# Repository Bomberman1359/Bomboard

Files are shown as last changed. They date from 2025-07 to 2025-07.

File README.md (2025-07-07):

# Bomboard
This is my cost efficient, custom keyboard made by me. As my first project, I named it Bomboard.

I made this project not only for the Highway programs, but also to gain experience in creating my own electronics.
I wanted to learn more about schematics, wiring, PCB, and 3D modeling. As someone that does not spend money on buying keyboards I figured it would be cool to create my own!

## Schematic
Screenshot 2025-07-03 at 6 05 30 PM

## PCB
Screenshot 2025-07-03 at 5 30 22 PM

## Case
Screenshot 2025-07-04 at 12 51 43 PM

## Case and PCB combined 
Screenshot 2025-07-06 at 5 43 42 PM

## BOM
| Item | Quantity | Vendor | Total Price |
| :--- | :---: | :----- | ---: |
| PCB | 1 | JLCPB | $74.23 |
| Raspberry Pi Pico | 1 | [Seeed Studio](https://www.seeedstudio.com/Raspberry-Pi-Pico-2-p-5940.html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) | $5.00 |
| Key switches |  64  |  [Mechanical](https://mechanicalkeyboards.com/products/cherry-mx2a-blue-60g-clicky?_pos=1&_fid=016d7ed23&_ss=c)| $25.60 |
| Rotary Encoder | 1 | [SynthCube](https://synthcube.com/rotary-encoder/?gQT=1) | $2.95 | 
| Stabilizer set | 1 | [Divinikey](https://jlcpcb.com/) | $11.00 |
| Keycaps Set| 1 | [Amazon](https://www.amazon.com/Womier-Pudding-Keycaps-100-Percent/dp/B0DB4Z6DMS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) | $14.99 |

Net Total Cost: $133.77

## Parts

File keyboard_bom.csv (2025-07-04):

Item | Quantity | Vendor | Total Price
PCB | 1 | JLCPB | $74.23
Raspberry Pi Pico | 1 | Seeed Studio | $5.00
Key switches | 64 | Mechanical | $25.60
Rotary Encoder | 1 | SynthCube | $2.95
Stabilizer set | 1 | Divinikey | $11.00
Keycaps Set | 1 | Amazon | $14.99
Net Total Cost |  |  | $133.77

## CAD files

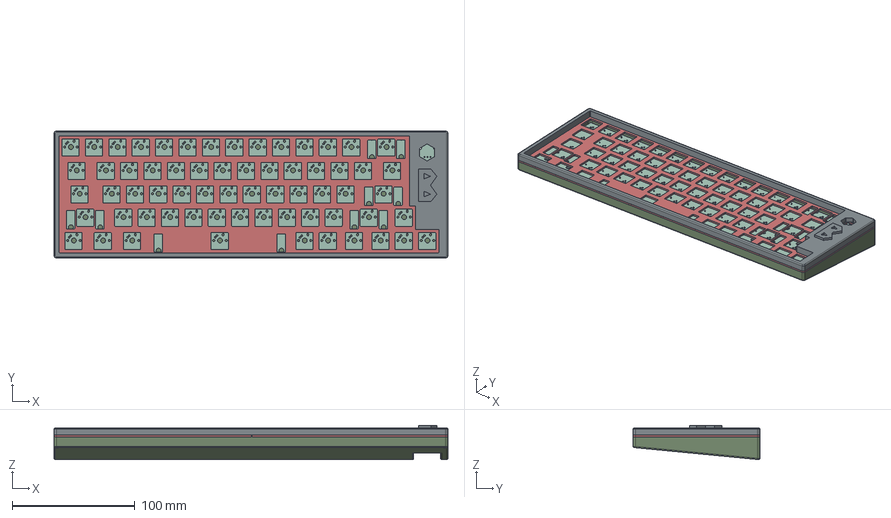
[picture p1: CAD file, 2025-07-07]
Case/keyboardCase_PCBassembly.step
321.0 x 103.5 x 27.9 mm
D_A-405_P7.62mm_Horizontal x 65
keyboard_PCB
Bottom
Top
Plate

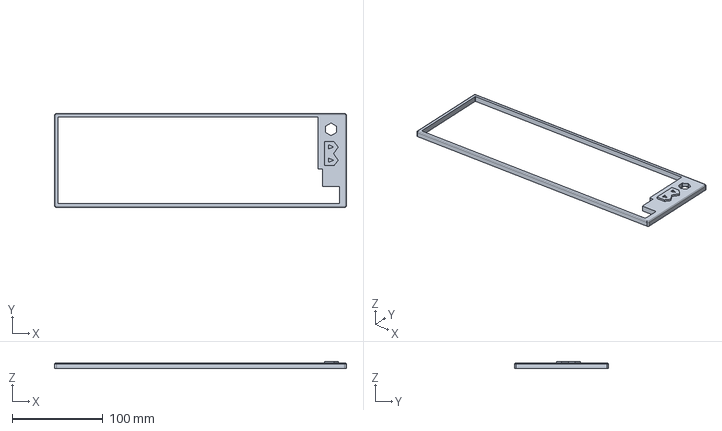
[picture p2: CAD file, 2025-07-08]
Production/3D-Printing (case)/Case_top.step
321.0 x 103.5 x 8.00 mm

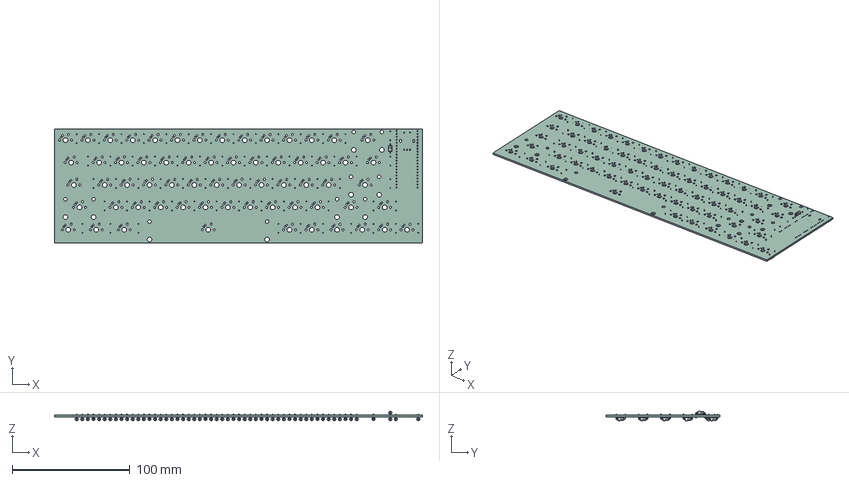
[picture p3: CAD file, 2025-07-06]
Case/keyboard.step
313.0 x 96.8 x 8.10 mm
D_A-405_P7.62mm_Horizontal x 65
keyboard_PCB

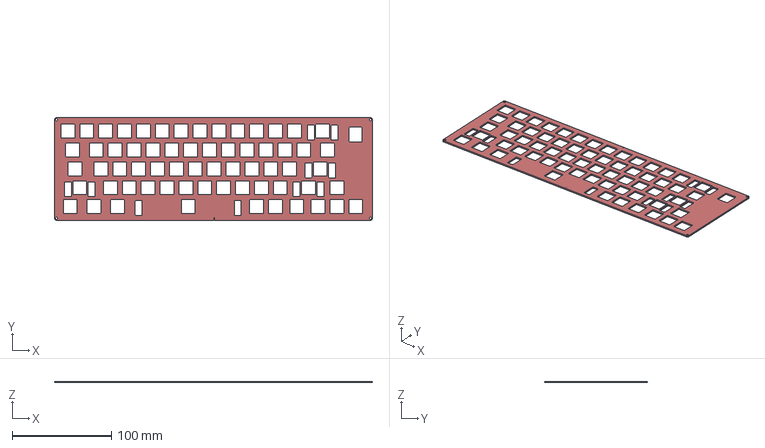
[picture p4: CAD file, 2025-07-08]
Production/3D-Printing (case)/Case_plate.step
321.0 x 103.5 x 1.50 mm

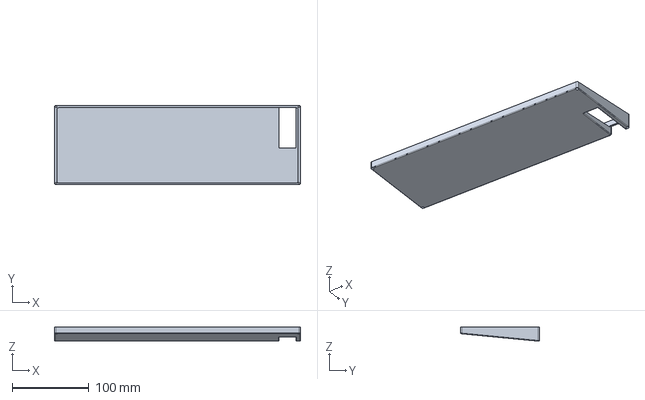
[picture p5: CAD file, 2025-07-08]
Production/3D-Printing (case)/Case_bottom.step
321.0 x 103.5 x 18.9 mm

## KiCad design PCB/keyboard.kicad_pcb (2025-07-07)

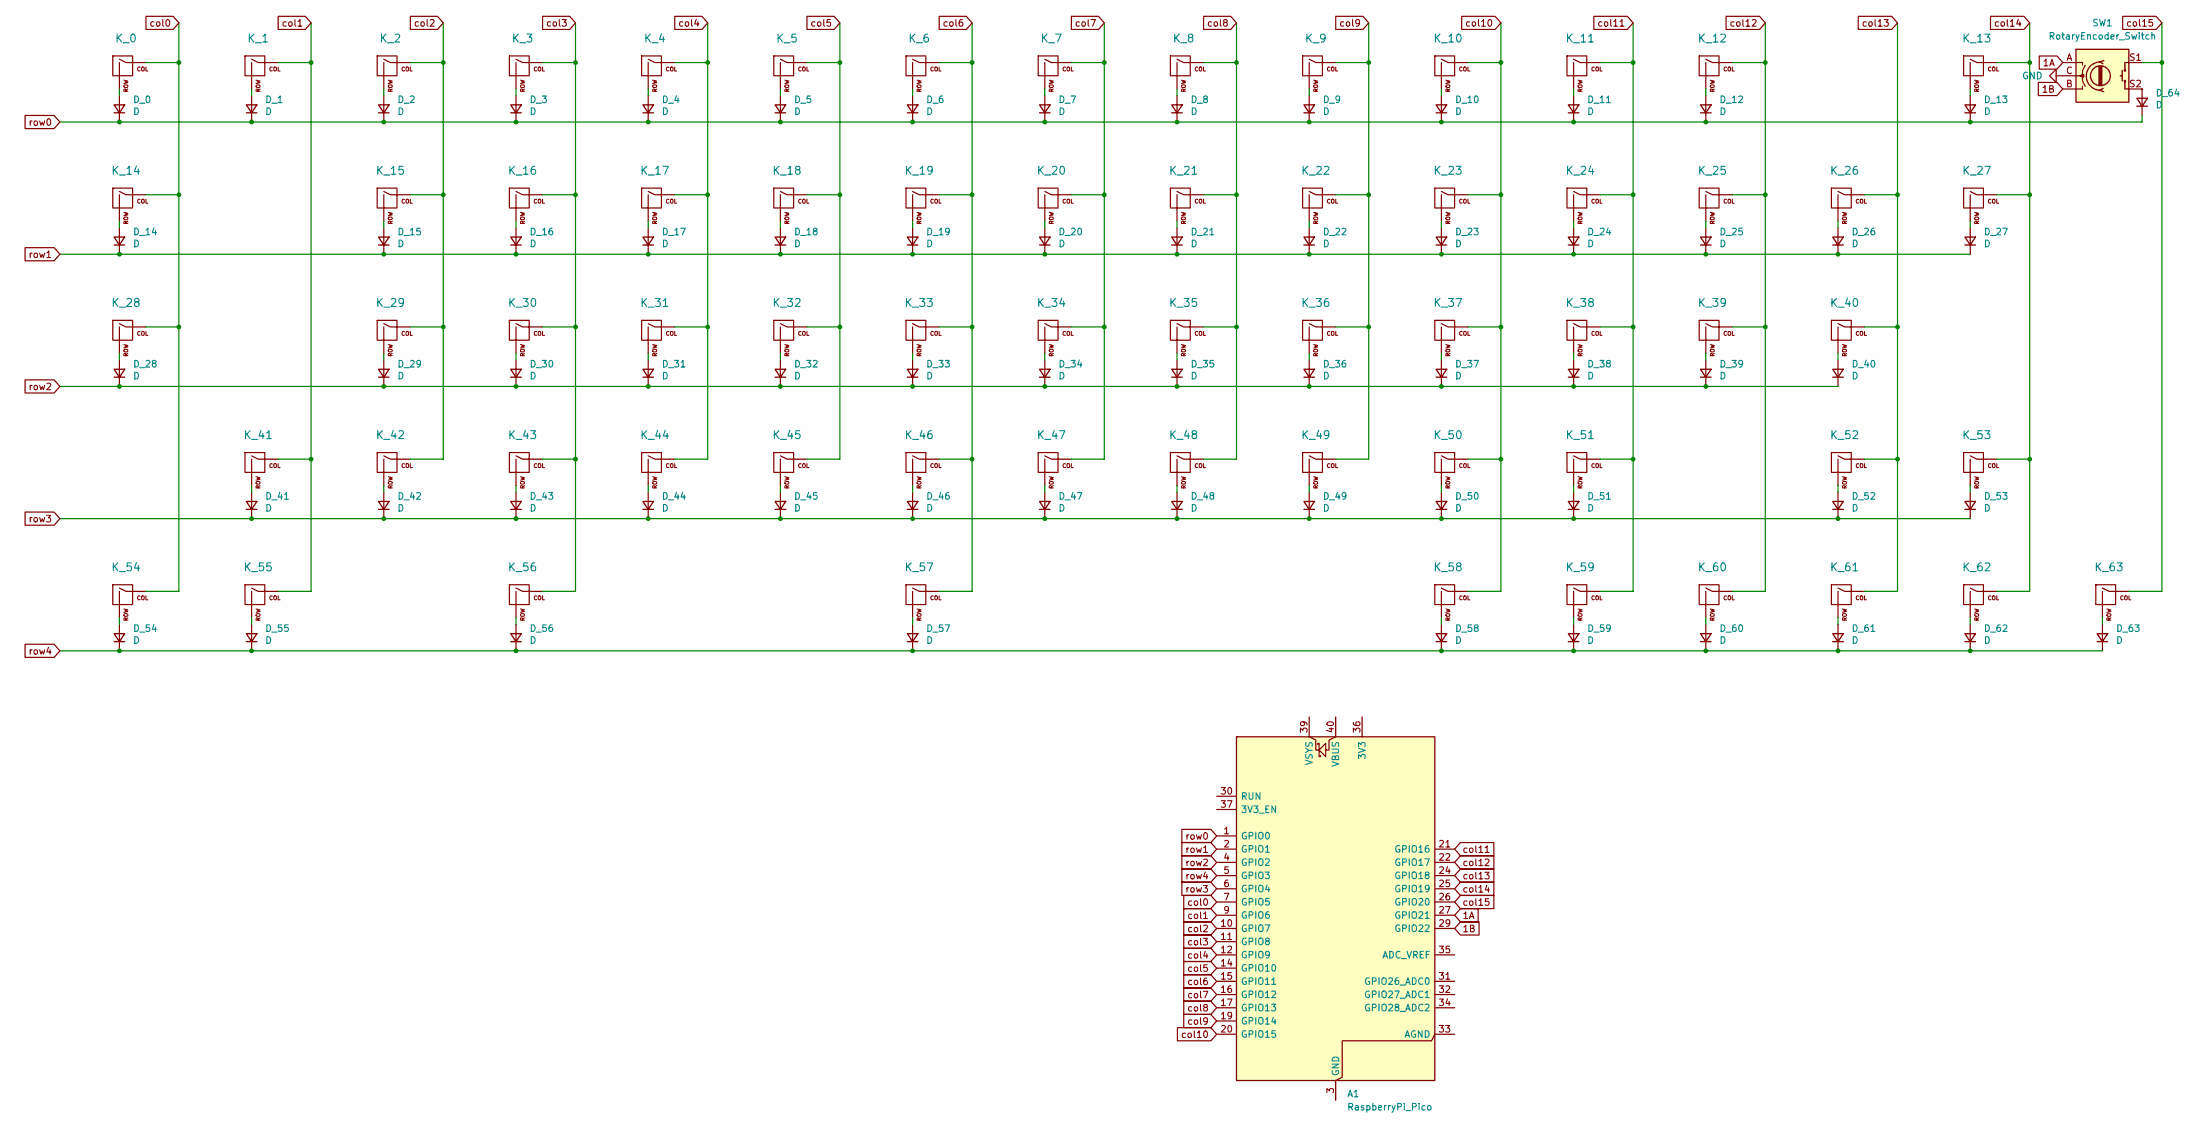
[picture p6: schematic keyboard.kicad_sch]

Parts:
A1: RaspberryPi_Pico; RaspberryPi_Pico_Common_THT
D_0, D_1, D_2, D_3, D_4, D_5, D_6, D_7, D_8, D_9, D_10, D_11, D_12, D_13, D_14, D_15, D_16, D_17, D_18, D_19, D_20, D_21, D_22, D_23, D_24, D_25, D_26, D_27, D_28, D_29, D_30, D_31, D_32, D_33, D_34, D_35, D_36, D_37, D_38, D_39, D_40, D_41, D_42, D_43, D_44, D_45, D_46, D_47, D_48, D_49, D_50, D_51, D_52, D_53, D_54, D_55, D_56, D_57, D_58, D_59, D_60, D_61, D_62, D_63, D_64: D; D_A-405_P7.62mm_Horizontal
K_0, K_1, K_2, K_3, K_4, K_5, K_6, K_7, K_8, K_9, K_10, K_11, K_12, K_15, K_16, K_17, K_18, K_19, K_20, K_21, K_22, K_23, K_24, K_25, K_26, K_29, K_30, K_31, K_32, K_33, K_34, K_35, K_36, K_37, K_38, K_39, K_42, K_43, K_44, K_45, K_46, K_47, K_48, K_49, K_50, K_51, K_53, K_58, K_59, K_61, K_62, K_63: KEYSW; MX-1U-NoLED
K_13, K_52: KEYSW; MX-2U-NoLED
K_14, K_27: KEYSW; MX-1.5U-NoLED
K_28: KEYSW; MX-1.75U-NoLED
K_40, K_41: KEYSW; MX-2.25U-NoLED
K_54, K_55, K_56, K_60: KEYSW; MX-1.25U-NoLED
K_57: KEYSW; MX-6.25U-NoLED
SW1: RotaryEncoder_Switch; RotaryEncoder_Alps_EC11E-Switch_Vertical_H20mm

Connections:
1A: A1.27 (GPIO21), SW1.A
1B: A1.29 (GPIO22), SW1.B
GND: SW1.C
unnamed: A1.3 (GND), A1.8 (GND), A1.13 (GND), A1.18 (GND), A1.23 (GND), A1.28 (GND), A1.38 (GND)
unnamed: D_0.2 (A), K_0.2 (ROW)
unnamed: D_1.2 (A), K_1.2 (ROW)
unnamed: D_2.2 (A), K_2.2 (ROW)
unnamed: D_3.2 (A), K_3.2 (ROW)
unnamed: D_4.2 (A), K_4.2 (ROW)
unnamed: D_5.2 (A), K_5.2 (ROW)
unnamed: D_6.2 (A), K_6.2 (ROW)
unnamed: D_7.2 (A), K_7.2 (ROW)
unnamed: D_8.2 (A), K_8.2 (ROW)
unnamed: D_9.2 (A), K_9.2 (ROW)
unnamed: D_10.2 (A), K_10.2 (ROW)
unnamed: D_11.2 (A), K_11.2 (ROW)
unnamed: D_12.2 (A), K_12.2 (ROW)
unnamed: D_13.2 (A), K_13.2 (ROW)
unnamed: D_14.2 (A), K_14.2 (ROW)
unnamed: D_15.2 (A), K_15.2 (ROW)
unnamed: D_16.2 (A), K_16.2 (ROW)
unnamed: D_17.2 (A), K_17.2 (ROW)
unnamed: D_18.2 (A), K_18.2 (ROW)
unnamed: D_19.2 (A), K_19.2 (ROW)
unnamed: D_20.2 (A), K_20.2 (ROW)
unnamed: D_21.2 (A), K_21.2 (ROW)
unnamed: D_22.2 (A), K_22.2 (ROW)
unnamed: D_23.2 (A), K_23.2 (ROW)
unnamed: D_24.2 (A), K_24.2 (ROW)
unnamed: D_25.2 (A), K_25.2 (ROW)
unnamed: D_26.2 (A), K_26.2 (ROW)
unnamed: D_27.2 (A), K_27.2 (ROW)
unnamed: D_28.2 (A), K_28.2 (ROW)
unnamed: D_29.2 (A), K_29.2 (ROW)
unnamed: D_30.2 (A), K_30.2 (ROW)
unnamed: D_31.2 (A), K_31.2 (ROW)
unnamed: D_32.2 (A), K_32.2 (ROW)
unnamed: D_33.2 (A), K_33.2 (ROW)
unnamed: D_34.2 (A), K_34.2 (ROW)
unnamed: D_35.2 (A), K_35.2 (ROW)
unnamed: D_36.2 (A), K_36.2 (ROW)
unnamed: D_37.2 (A), K_37.2 (ROW)
unnamed: D_38.2 (A), K_38.2 (ROW)
unnamed: D_39.2 (A), K_39.2 (ROW)
unnamed: D_40.2 (A), K_40.2 (ROW)
unnamed: D_41.2 (A), K_41.2 (ROW)
unnamed: D_42.2 (A), K_42.2 (ROW)
unnamed: D_43.2 (A), K_43.2 (ROW)
unnamed: D_44.2 (A), K_44.2 (ROW)
unnamed: D_45.2 (A), K_45.2 (ROW)
unnamed: D_46.2 (A), K_46.2 (ROW)
unnamed: D_47.2 (A), K_47.2 (ROW)
unnamed: D_48.2 (A), K_48.2 (ROW)
unnamed: D_49.2 (A), K_49.2 (ROW)
unnamed: D_50.2 (A), K_50.2 (ROW)
unnamed: D_51.2 (A), K_51.2 (ROW)
unnamed: D_52.2 (A), K_52.2 (ROW)
unnamed: D_53.2 (A), K_53.2 (ROW)
unnamed: D_54.2 (A), K_54.2 (ROW)
unnamed: D_55.2 (A), K_55.2 (ROW)
unnamed: D_56.2 (A), K_56.2 (ROW)
unnamed: D_57.2 (A), K_57.2 (ROW)
unnamed: D_58.2 (A), K_58.2 (ROW)
unnamed: D_59.2 (A), K_59.2 (ROW)
unnamed: D_60.2 (A), K_60.2 (ROW)
unnamed: D_61.2 (A), K_61.2 (ROW)
unnamed: D_62.2 (A), K_62.2 (ROW)
unnamed: D_63.2 (A), K_63.2 (ROW)
unnamed: D_64.2 (A), SW1.S2
col0: A1.7 (GPIO5), K_0.1 (COL), K_14.1 (COL), K_28.1 (COL), K_54.1 (COL)
col1: A1.9 (GPIO6), K_1.1 (COL), K_41.1 (COL), K_55.1 (COL)
col2: A1.10 (GPIO7), K_2.1 (COL), K_15.1 (COL), K_29.1 (COL), K_42.1 (COL)
col3: A1.11 (GPIO8), K_3.1 (COL), K_16.1 (COL), K_30.1 (COL), K_43.1 (COL), K_56.1 (COL)
col4: A1.12 (GPIO9), K_4.1 (COL), K_17.1 (COL), K_31.1 (COL), K_44.1 (COL)
col5: A1.14 (GPIO10), K_5.1 (COL), K_18.1 (COL), K_32.1 (COL), K_45.1 (COL)
col6: A1.15 (GPIO11), K_6.1 (COL), K_19.1 (COL), K_33.1 (COL), K_46.1 (COL), K_57.1 (COL)
col7: A1.16 (GPIO12), K_7.1 (COL), K_20.1 (COL), K_34.1 (COL), K_47.1 (COL)
col8: A1.17 (GPIO13), K_8.1 (COL), K_21.1 (COL), K_35.1 (COL), K_48.1 (COL)
col9: A1.19 (GPIO14), K_9.1 (COL), K_22.1 (COL), K_36.1 (COL), K_49.1 (COL)
col10: A1.20 (GPIO15), K_10.1 (COL), K_23.1 (COL), K_37.1 (COL), K_50.1 (COL), K_58.1 (COL)
col11: A1.21 (GPIO16), K_11.1 (COL), K_24.1 (COL), K_38.1 (COL), K_51.1 (COL), K_59.1 (COL)
col12: A1.22 (GPIO17), K_12.1 (COL), K_25.1 (COL), K_39.1 (COL), K_60.1 (COL)
col13: A1.24 (GPIO18), K_26.1 (COL), K_40.1 (COL), K_52.1 (COL), K_61.1 (COL)
col14: A1.25 (GPIO19), K_13.1 (COL), K_27.1 (COL), K_53.1 (COL), K_62.1 (COL)
col15: A1.26 (GPIO20), K_63.1 (COL), SW1.S1
row0: A1.1 (GPIO0), D_0.1 (K), D_1.1 (K), D_2.1 (K), D_3.1 (K), D_4.1 (K), D_5.1 (K), D_6.1 (K), D_7.1 (K), D_8.1 (K), D_9.1 (K), D_10.1 (K), D_11.1 (K), D_12.1 (K), D_13.1 (K), D_64.1 (K)
row1: A1.2 (GPIO1), D_14.1 (K), D_15.1 (K), D_16.1 (K), D_17.1 (K), D_18.1 (K), D_19.1 (K), D_20.1 (K), D_21.1 (K), D_22.1 (K), D_23.1 (K), D_24.1 (K), D_25.1 (K), D_26.1 (K), D_27.1 (K)
row2: A1.4 (GPIO2), D_28.1 (K), D_29.1 (K), D_30.1 (K), D_31.1 (K), D_32.1 (K), D_33.1 (K), D_34.1 (K), D_35.1 (K), D_36.1 (K), D_37.1 (K), D_38.1 (K), D_39.1 (K), D_40.1 (K)
row3: A1.6 (GPIO4), D_41.1 (K), D_42.1 (K), D_43.1 (K), D_44.1 (K), D_45.1 (K), D_46.1 (K), D_47.1 (K), D_48.1 (K), D_49.1 (K), D_50.1 (K), D_51.1 (K), D_52.1 (K), D_53.1 (K)
row4: A1.5 (GPIO3), D_54.1 (K), D_55.1 (K), D_56.1 (K), D_57.1 (K), D_58.1 (K), D_59.1 (K), D_60.1 (K), D_61.1 (K), D_62.1 (K), D_63.1 (K)

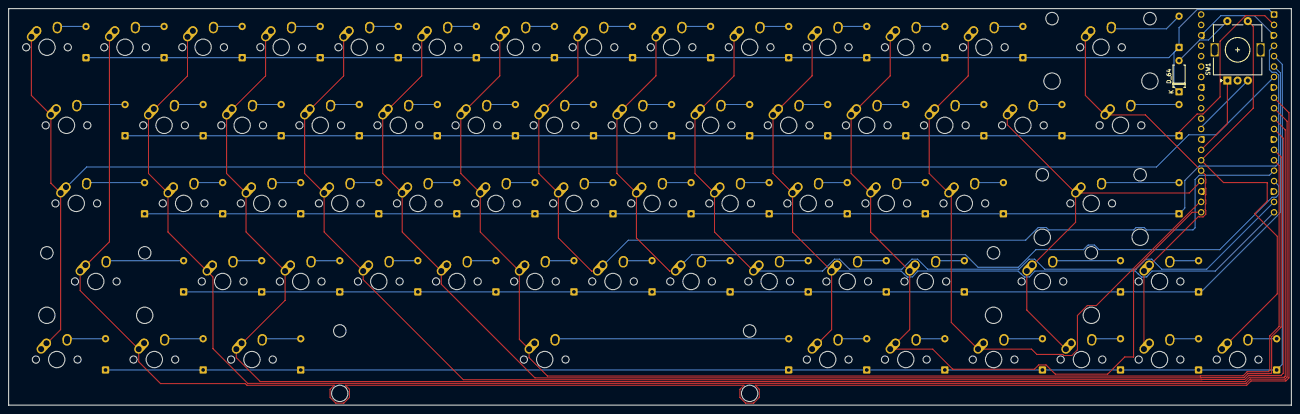
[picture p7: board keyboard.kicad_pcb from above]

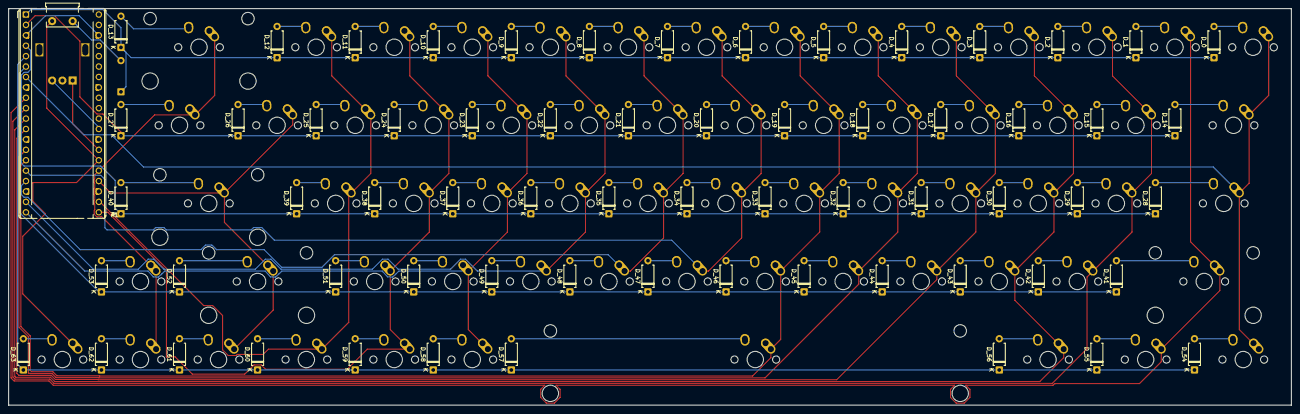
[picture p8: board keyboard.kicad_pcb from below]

Board: 2 copper layers, 313.0 x 96.8 mm, 131 parts (65 on the bottom side), 89 nets.

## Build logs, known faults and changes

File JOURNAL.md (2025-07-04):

---
Title: "Bomboard"
Author: "Chunhwee Choi"
Description: "Basic custom keyboard"
Created_at: "2025-06-20"
---
# Design Journal
Total Number of Hours Spent: 25 Hours

## Fresh Start: 6/20/2025, 4 Hours
I started off the basic design using the [Keyboard Layout Editor](https://www.keyboard-layout-editor.com/) to obtain raw data for the schematics.

Screenshot 2025-07-04 at 11 58 25 AM

Screenshot 2025-07-03 at 6 05 39 PM

These are the final results. The schematics took some time to figure out, but the actual wiring was just busy work. I also decided to add a knob for extra complexity and to make it seem more cooler. 

## PCB: 6/22/2025 - 6/24/2025, 11 Hours
As I uploaded my schematics to generate the PCB, my first step was to create the outline for the board. I had to make sure there was enough space for any wiring, rotary encoder, the usb port, and the knob. 
I also had to shift all the diodes in a way that would make the wiring simpler for me. 
The routing was the most tedious and complicated part. I had to constantly make changes to my previous wires due to the fact that I had to efficiently make use of the little space I had as much as possible.

Here is the final product (I forgot to take pictures of the process):
Screenshot 2025-07-03 at 5 30 22 PM

## CAD: 6/25/2025 - 6/28/2025, 10 Hours
I first started off with the plate of the keyboard using dimension tools:
Screenshot 2025-07-04 at 12 45 27 PM

Based off the plate, I created the bottom and the top part of the keyboard case respectively using various onshape features:

Screenshot 2025-07-04 at 12 47 58 PM
Screenshot 2025-07-04 at 12 48 50 PM

I decided to add a simple, geometric B at the remaining space I had on the top of my case for customization purposes.

This is the final, combined picture of the case:
Screenshot 2025-07-04 at 12 51 43 PM

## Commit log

2025-07-04 Add files via upload
    Actual CAD information
2025-07-07 Adding the PCB file with all of the PCB information
    [keyboard.kicad_pcb, keyboard.kicad_sch, keyboard.sch]
2025-07-07 Organizing everything into the firmware and case files
    [keyboard.step]
2025-07-08 Adding step files of the different parts of the case
    [Case_bottom.step, Case_plate.step, Case_top.step]
